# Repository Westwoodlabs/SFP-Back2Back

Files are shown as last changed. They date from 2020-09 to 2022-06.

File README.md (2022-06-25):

# SFP Back2Back V2

Bridges two small Form-factor Pluggable (SFP, Mini-GBIC) Modules together. This PCB makes it possible, for example, to switch from multi-mode to single-mode if one side has a built-in multi-mode transceiver, the range can be increased with a single-mode connection.  

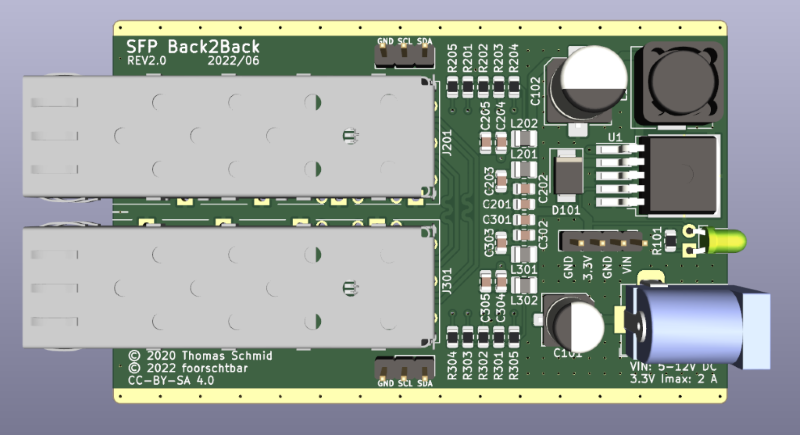
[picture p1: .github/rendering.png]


## PCB
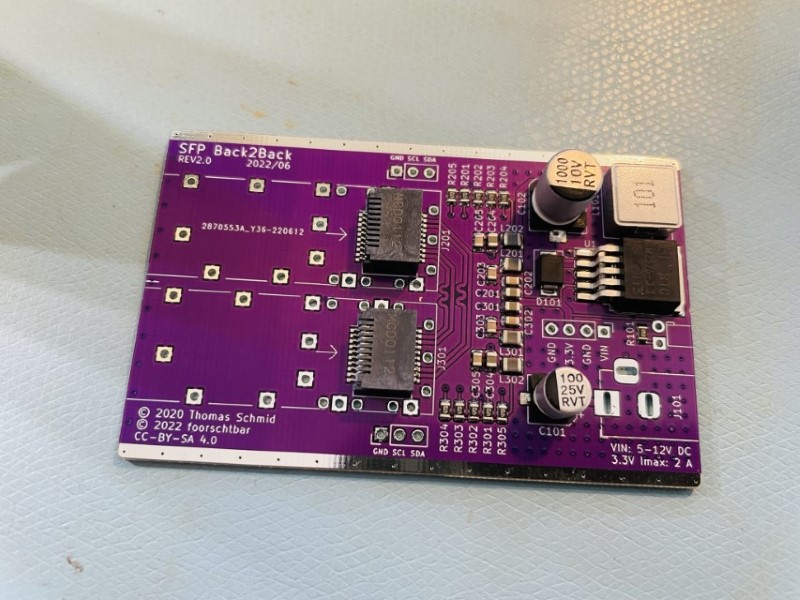
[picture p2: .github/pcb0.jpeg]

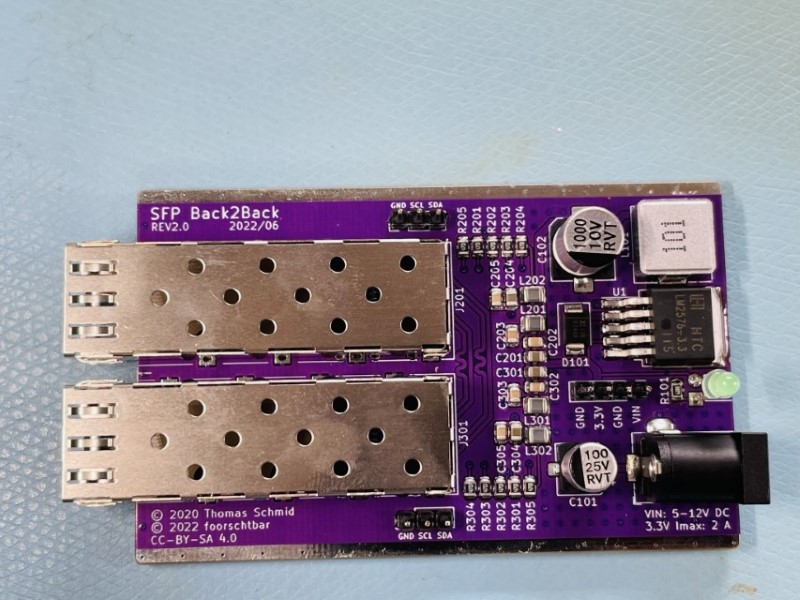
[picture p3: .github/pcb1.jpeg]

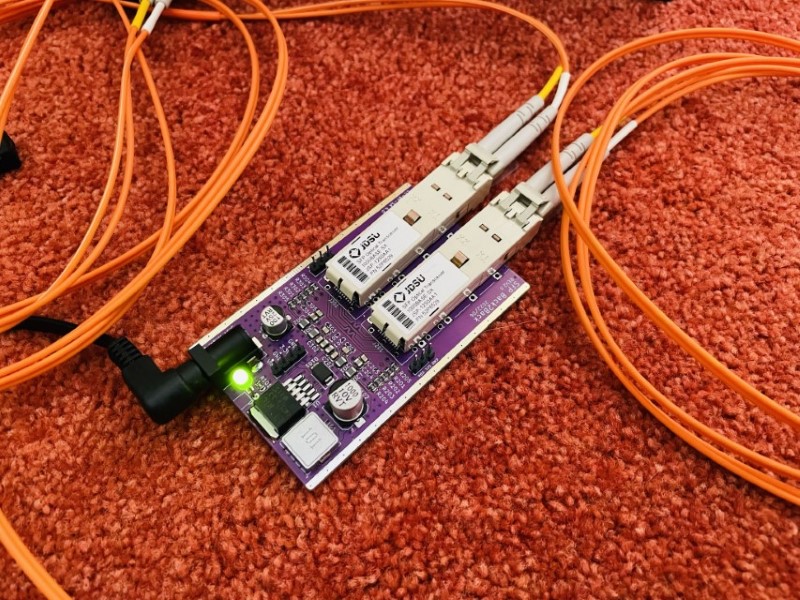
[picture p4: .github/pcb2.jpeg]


## Case
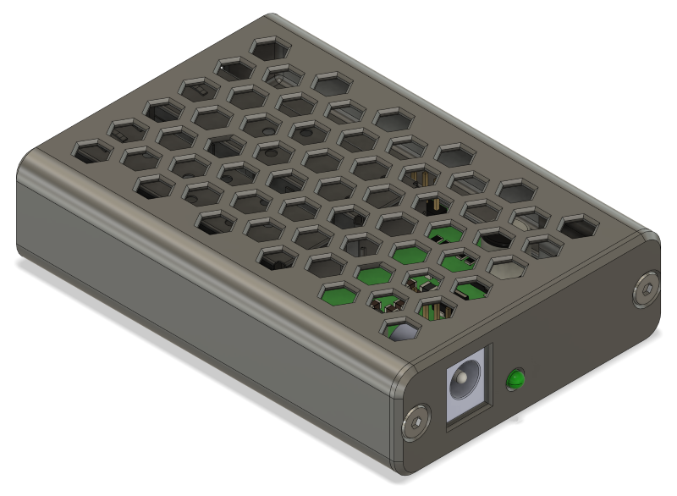
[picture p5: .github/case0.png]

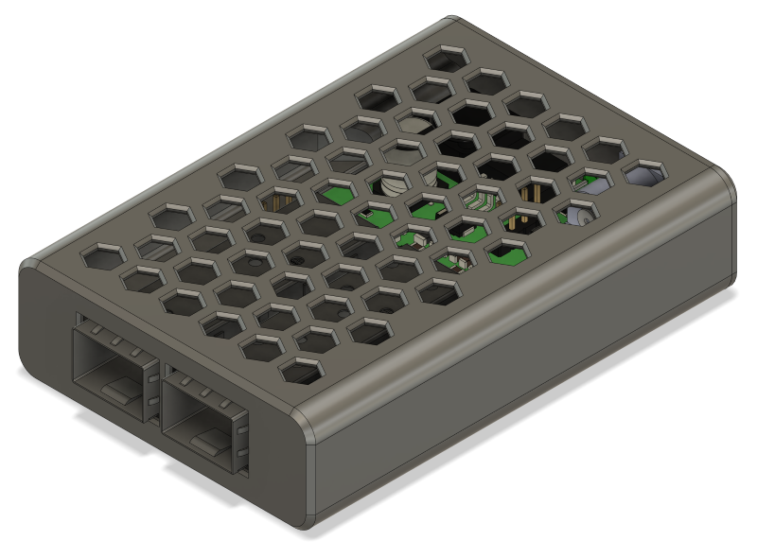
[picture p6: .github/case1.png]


## Credits

This is a revised version of [git.binary-kitchen.de/tom/sfp_back2back](https://git.binary-kitchen.de/tom/sfp_back2back), because due to the global chip shortage in 2022 a change of the components was necessary. In this same process, small improvements were also made (Routing, I2C Headers, upgrade to 0805).

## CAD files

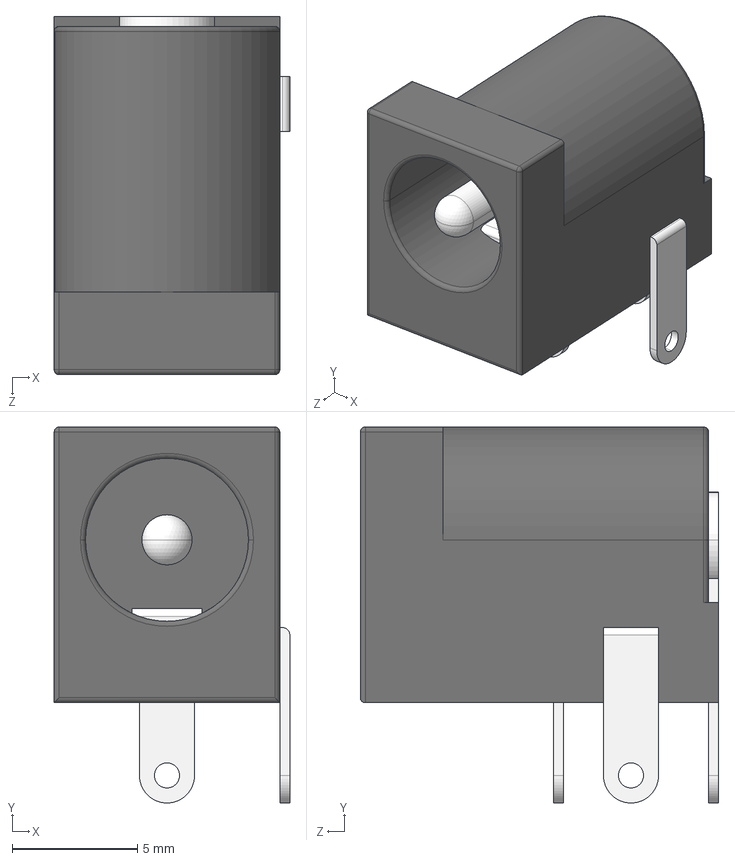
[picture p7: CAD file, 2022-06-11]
3d-models/dc_jack.STEP
9.40 x 15.0 x 14.3 mm

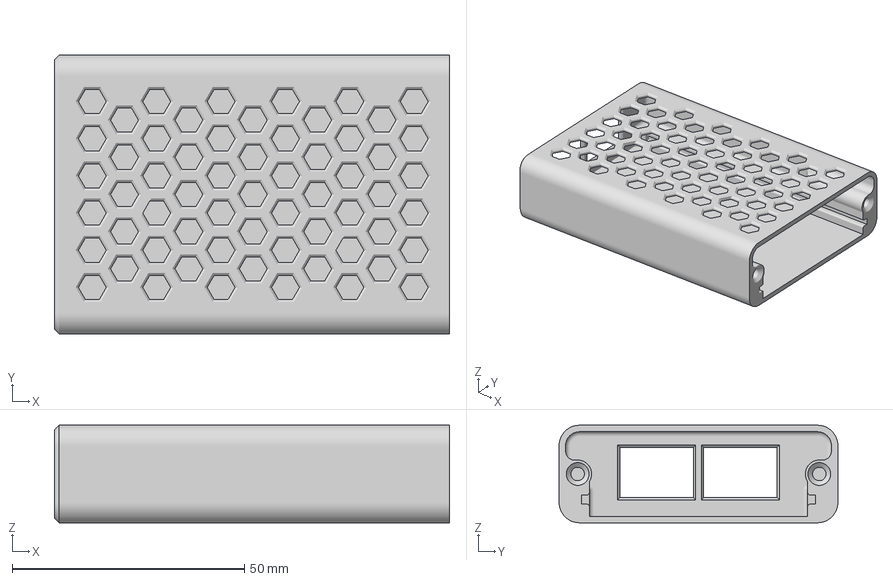
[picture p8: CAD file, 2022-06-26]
case/SFP-B2B-Body-F360.3mf
85.0 x 60.0 x 21.0 mm

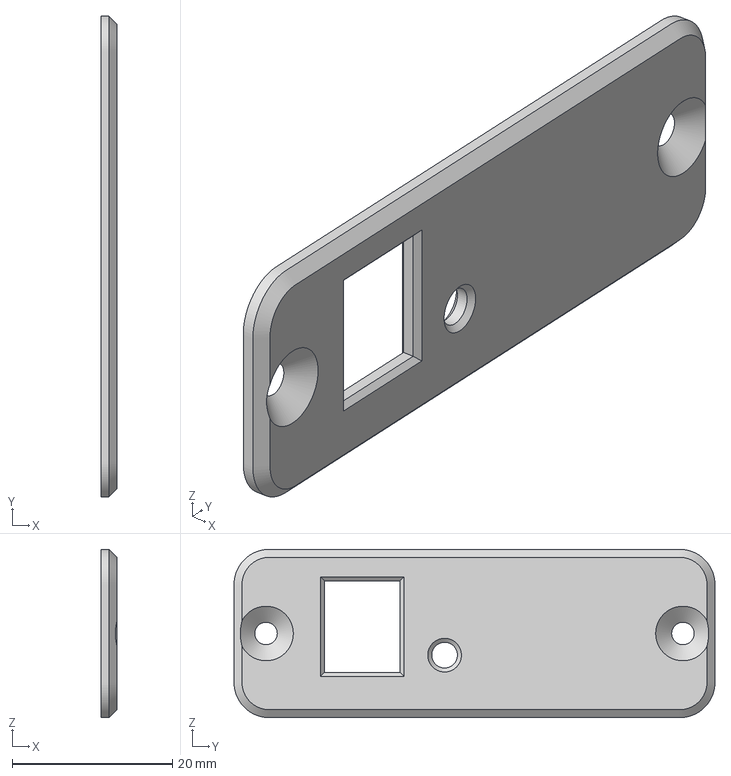
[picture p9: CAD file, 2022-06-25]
case/SFP-B2B-Panel-F360.3mf
2.00 x 60.0 x 21.0 mm

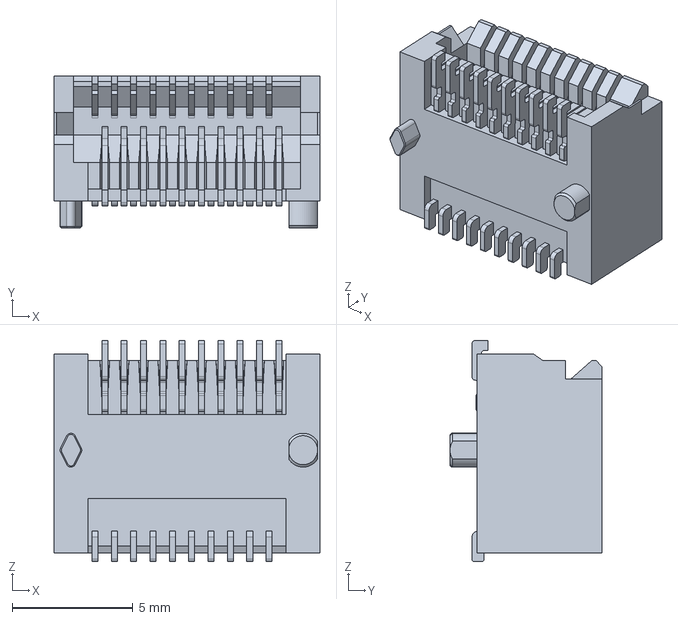
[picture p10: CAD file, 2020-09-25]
3d-models/744410001.stp
11.0 x 6.27 x 9.15 mm

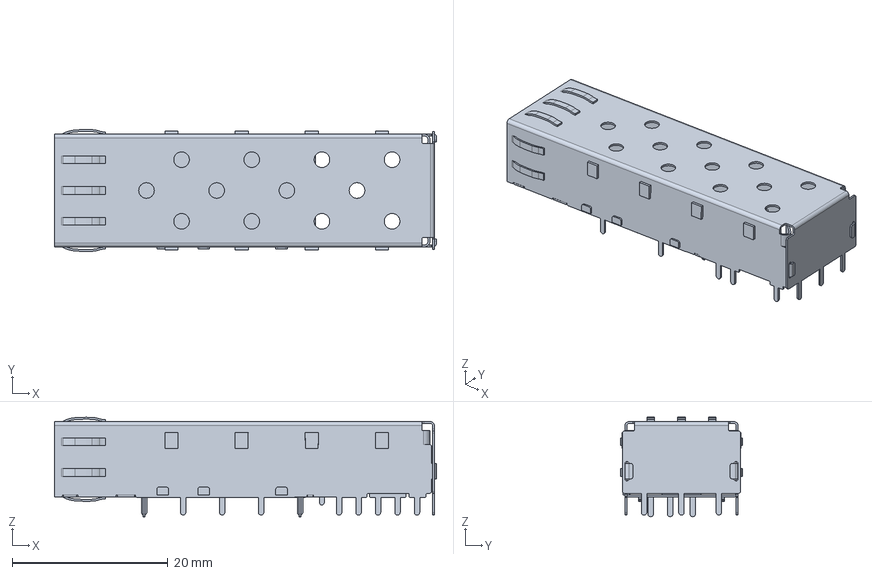
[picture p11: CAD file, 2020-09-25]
3d-models/747370002.stp
49.0 x 15.6 x 12.8 mm

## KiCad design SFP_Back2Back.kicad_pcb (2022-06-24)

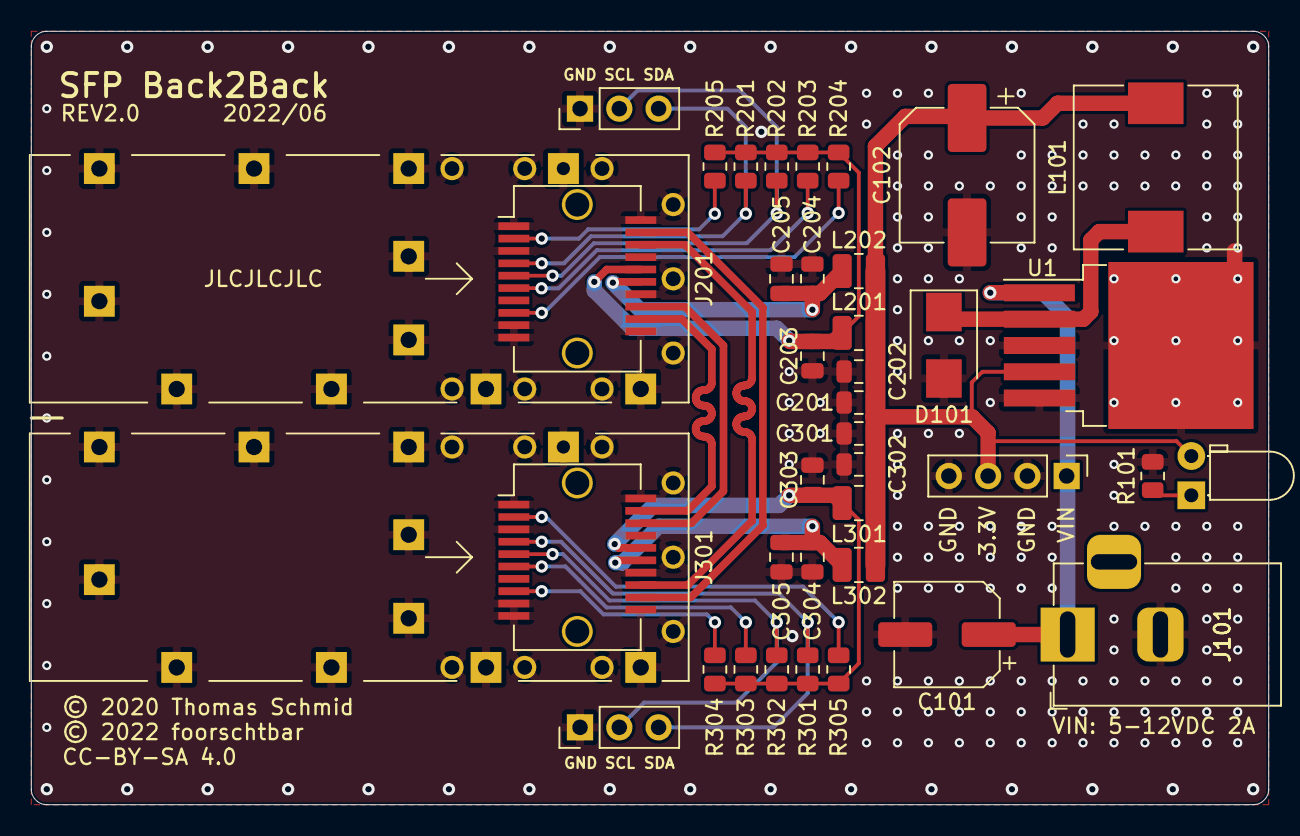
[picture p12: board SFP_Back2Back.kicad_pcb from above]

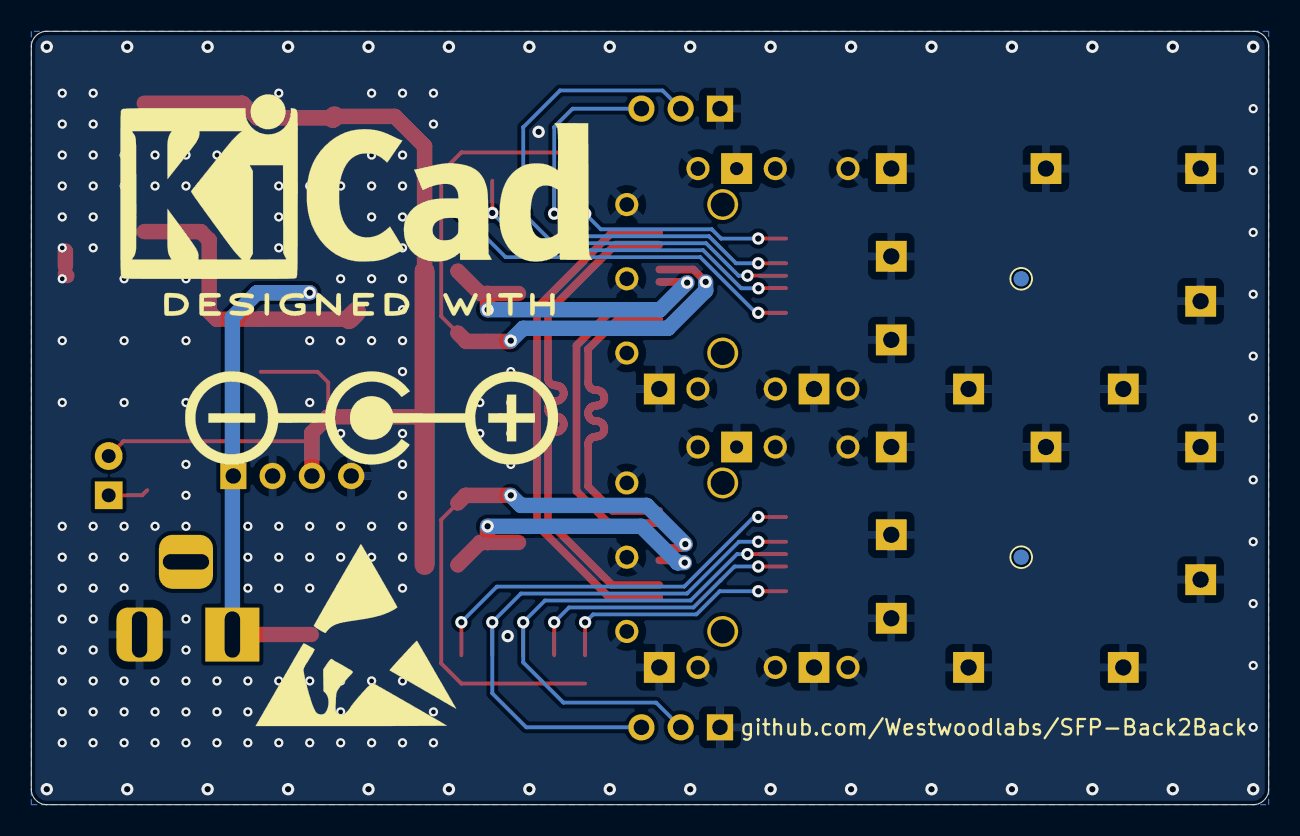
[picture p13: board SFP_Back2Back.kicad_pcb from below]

Board: 2 copper layers, 80.0 x 50.0 mm, 39 parts (2 on the bottom side), 23 nets.

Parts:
C101: 100uF; CP_Elec_6.3x7.7
C102: 1000uF; CP_Elec_8x10.5
C201, C204, C301, C304: 10uF; C_0805_2012Metric
C202, C203, C205, C302, C303, C305: 100nF; C_0805_2012Metric
D101: B340B-13-F; D_SMB
D103: LED; LED_D3.0mm_Horizontal_O1.27mm_Z2.0mm
J1: Conn_01x04; PinHeader_1x04_P2.54mm_Vertical
J2, J3: Conn_01x03; PinHeader_1x03_P2.54mm_Vertical
J101: Barrel_Jack; BarrelJack_Horizontal
J201, J301: SFP; Connector_SFP_and_Cage
L101: 100uH; L_10.4x10.4_H4.8
L201, L202, L301, L302: 1uH; L_1008_2520Metric
N1, N2: Housing_Pad; TestPoint_Pad_D1.0mm
R101: 68R; R_0805_2012Metric
R201, R202, R203, R204, R205, R301, R302, R303, R304, R305: 4.7k; R_0805_2012Metric
U1: LM2576S-3.3; TO-263-5_TabPin3

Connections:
+3V3: C102.1, C201.1, C202.1, C301.1, C302.1, D103.2 (A), J1.3, L101.2, L201.1, L202.1, L301.1, L302.1, U1.4 (FB)
/Vin: C101.1, J1.1, J101.1, U1.1 (VIN)
/sfp_module_1/MOD_DEF1_SCL: J2.2, J301.5 (MOD_DEF1), R302.1
/sfp_module_1/MOD_DEF2_SDA: J2.3, J301.4 (MOD_DEF2), R301.1
/sfp_module_1/RX+: J201.18 (TD+), J301.13 (RD+)
/sfp_module_1/RX-: J201.19 (TD-), J301.12 (RD-)
/sfp_module_1/RX_LOS: J301.8 (RX_LOS), R304.1
/sfp_module_1/TX+: J201.13 (RD+), J301.18 (TD+)
/sfp_module_1/TX-: J201.12 (RD-), J301.19 (TD-)
/sfp_module_1/TX_FAULT: J301.2 (TX_FAULT), R305.2
/sfp_module_1/VCC_R: C304.1, C305.1, J301.15 (VccR), L302.2
/sfp_module_1/VCC_T: C303.1, J301.16 (VccT), L301.2, R301.2, R302.2, R303.2, R304.2, R305.1
/sfp_module_2/MOD_DEF1_SCL: J3.2, J201.5 (MOD_DEF1), R202.1
/sfp_module_2/MOD_DEF2_SDA: J3.3, J201.4 (MOD_DEF2), R201.1
/sfp_module_2/RX_LOS: J201.8 (RX_LOS), R204.1
/sfp_module_2/TX_FAULT: J201.2 (TX_FAULT), R205.2
/sfp_module_2/VCC_R: C204.1, C205.1, J201.15 (VccR), L202.2
/sfp_module_2/VCC_T: C203.1, J201.16 (VccT), L201.2, R201.2, R202.2, R203.2, R204.2, R205.1
GND: C101.2, C102.2, C201.2, C202.2, C203.2, C204.2, C205.2, C301.2, C302.2, C303.2, C304.2, C305.2, D101.2 (A), J1.2, J1.4, J2.1, J3.1, J101.2, J201.1 (VeeT), J201.3 (TX_DISABLE), J201.9 (VeeR), J201.10 (VeeR), J201.11 (VeeR), J201.14 (VeeR), J201.17 (VeeT), J201.20 (VeeT), J201.CAGE, J301.1 (VeeT), J301.3 (TX_DISABLE), J301.9 (VeeR), J301.10 (VeeR), J301.11 (VeeR), J301.14 (VeeR), J301.17 (VeeT), J301.20 (VeeT), J301.CAGE, R101.2, U1.3 (GND), U1.5 (~ON/OFF)
unnamed: D101.1 (K), L101.1, U1.2 (OUT)
unnamed: D103.1 (K), R101.1
unnamed: J201.6 (MOD_DEF0), R203.1
unnamed: J301.6 (MOD_DEF0), R303.1

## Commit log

2020-11-29 finish layout
    [poc_sfp_b2b.kicad_pcb]
2021-01-10 fix unconnected tx disable pin
    [poc_sfp_b2b.kicad_pcb, poc_sfp_b2b.sch, sfp_module.sch]
2021-01-26 add cad files for case
    [poc_sfp_back2back_case.FCStd]
2022-05-19 Converter to KiCad 6 and added Symbol for alternative Buck-Converter
    [poc_sfp_b2b.kicad_pcb, poc_sfp_b2b.kicad_sch, poc_sfp_b2b.sch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]
2022-05-19 Replaced Mouser with LCSC Components
    [poc_sfp_b2b.kicad_pcb, poc_sfp_b2b.kicad_sch, sfp_module.kicad_sch]
2022-05-28 Added I2C pins
    [poc_sfp_b2b.kicad_pcb, poc_sfp_b2b.kicad_sch, sfp_module.kicad_sch]
2022-06-11 Added DC Jack 3D Model
    [dc_jack.STEP]
2022-06-11 Added Case
    [SFP Back2Back Case Body.step, SFP Back2Back Case Body.stl, SFP Back2Back Case Panel.step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]
2022-06-11 Moved Case STLs
    [SFP Back2Back Case Body.step, SFP Back2Back Case Body.stl, SFP Back2Back Case Panel.step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]
2022-06-11 Removed old BOM
2022-06-11 Finished PCB and renamed it
    [SFP_Back2Back.kicad_pcb, SFP_Back2Back.kicad_sch, poc_sfp_b2b.kicad_pcb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]
2022-06-11 Added Gerber files
    [SFP_Back2Back-B_Cu.gbr, SFP_Back2Back-B_Mask.gbr, SFP_Back2Back-B_Paste.gbr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]
2022-06-11 Fixed Caps Voltage
    [SFP_Back2Back-B_Cu.gbr, SFP_Back2Back-B_Mask.gbr, SFP_Back2Back-B_Paste.gbr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]
2022-06-24 Fixed LCSC Order Number for 68R Resistor
    [SFP_Back2Back.kicad_pcb, SFP_Back2Back.kicad_sch]
2022-06-25 Added new housing/case
    [SFP Back2Back Case Body.step, SFP Back2Back Case Body.stl, SFP Back2Back Case Panel.step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]
2022-06-26 Minor changes at the case
    [SFP-B2B-Body-F360.3mf]

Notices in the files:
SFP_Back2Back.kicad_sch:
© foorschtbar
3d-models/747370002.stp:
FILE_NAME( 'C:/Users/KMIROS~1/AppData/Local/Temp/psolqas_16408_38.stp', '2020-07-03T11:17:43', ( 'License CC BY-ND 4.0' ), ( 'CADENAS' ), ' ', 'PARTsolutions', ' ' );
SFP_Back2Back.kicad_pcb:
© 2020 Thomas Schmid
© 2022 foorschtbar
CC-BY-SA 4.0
